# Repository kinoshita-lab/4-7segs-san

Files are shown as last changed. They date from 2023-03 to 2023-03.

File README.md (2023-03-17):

# 4-7segs-san kit

[Document in Japanese](README_ja.md)

4-7segs-san is a handy PCB with 4-digit 7-segment LEDs with decimal point.
You can speed up your MCU project with displaying numbers such as BPM, Level, etc.

## Main Features

- Only 2 GPIO pins required, connected to built in LED Driver(TM1640)
- Compatible for both 5V and 3.3V with builting buffers for signal,  DC-DC converter for power sourcing.
- Easy to use with [dedicated Arduino library for TM1640](./soft/4-7segs-san/TM1640.h)

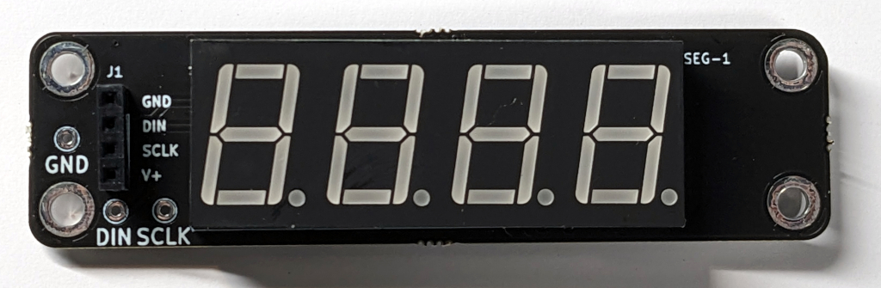
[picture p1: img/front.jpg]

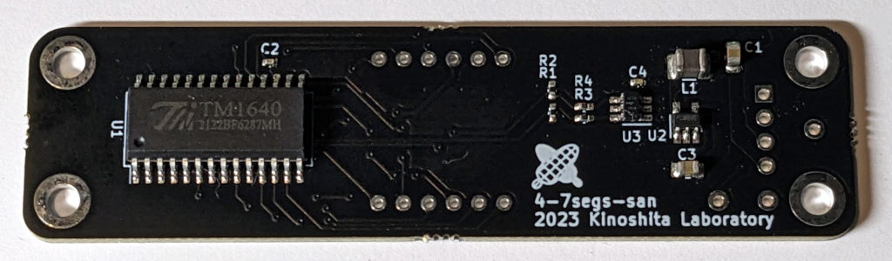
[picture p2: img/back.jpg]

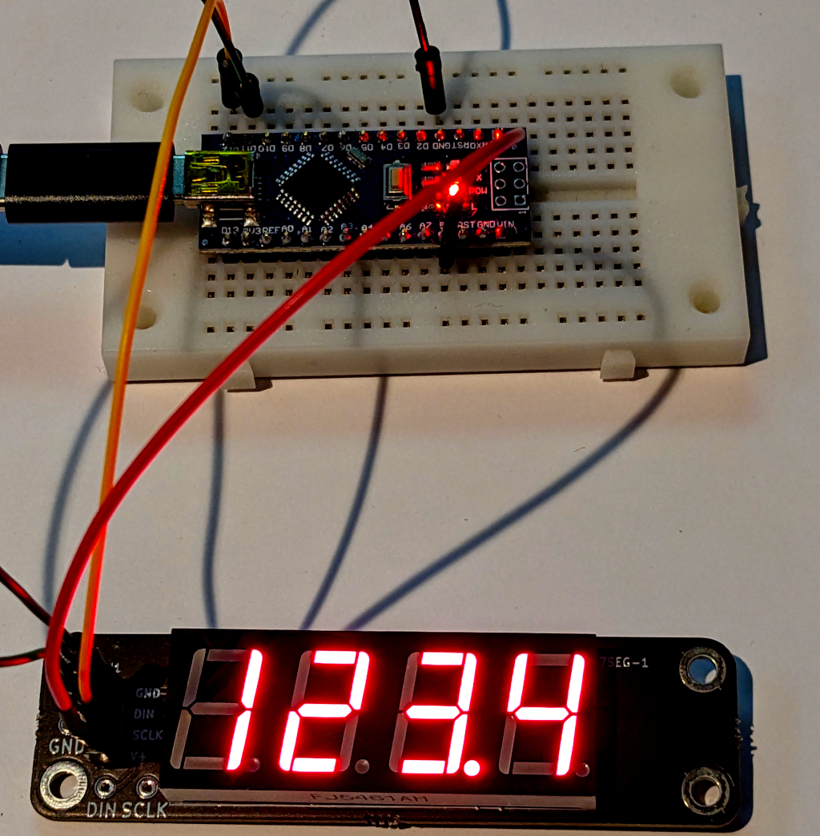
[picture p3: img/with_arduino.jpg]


## Kit Contents

- Pre-assembled circuit board
- [4 digit common cathode segment display](https://www.lcsc.com/product-detail/_Shenzhen-Zhihao-Elec-_C54396.html)
- 1x4 pin socket

## How to assemble

1. Cut all the pins on LED display to approx. 5mm for easier handling.
2. Solder the LED display and pin socket

## Sample program

Please refer to the [soft/4-7segs-san](soft/4-7segs-san)

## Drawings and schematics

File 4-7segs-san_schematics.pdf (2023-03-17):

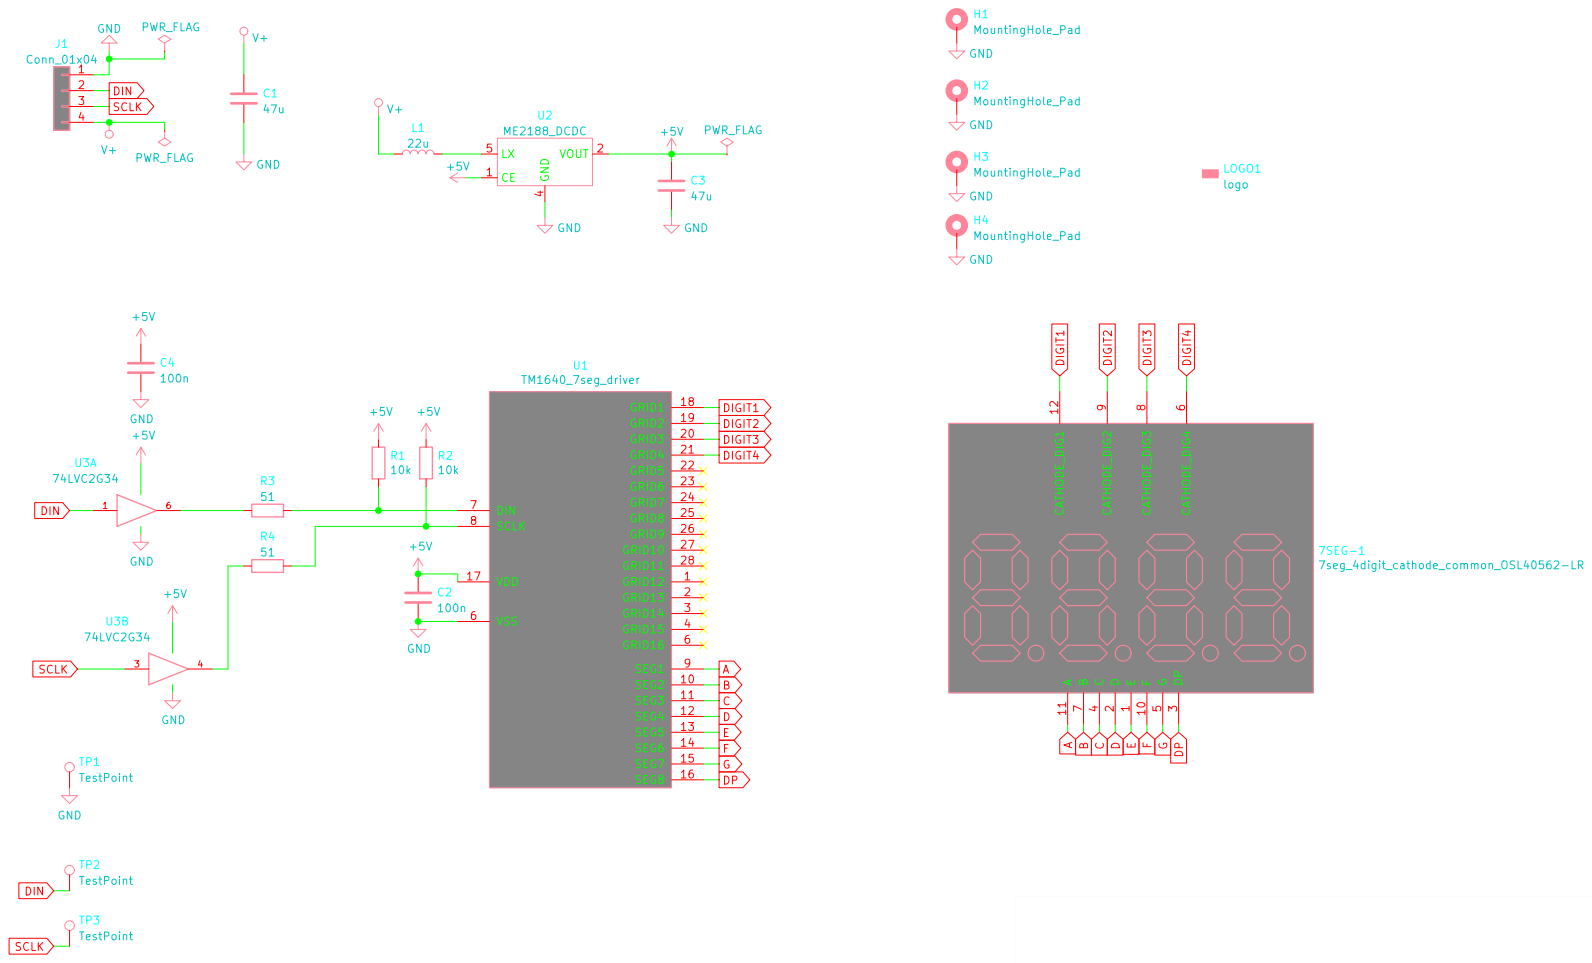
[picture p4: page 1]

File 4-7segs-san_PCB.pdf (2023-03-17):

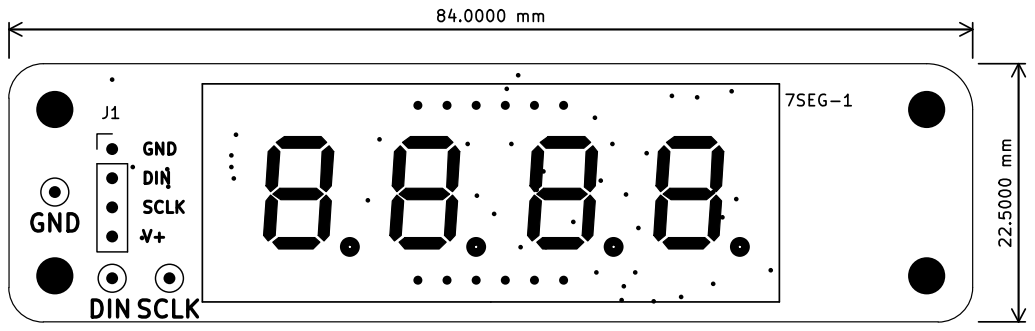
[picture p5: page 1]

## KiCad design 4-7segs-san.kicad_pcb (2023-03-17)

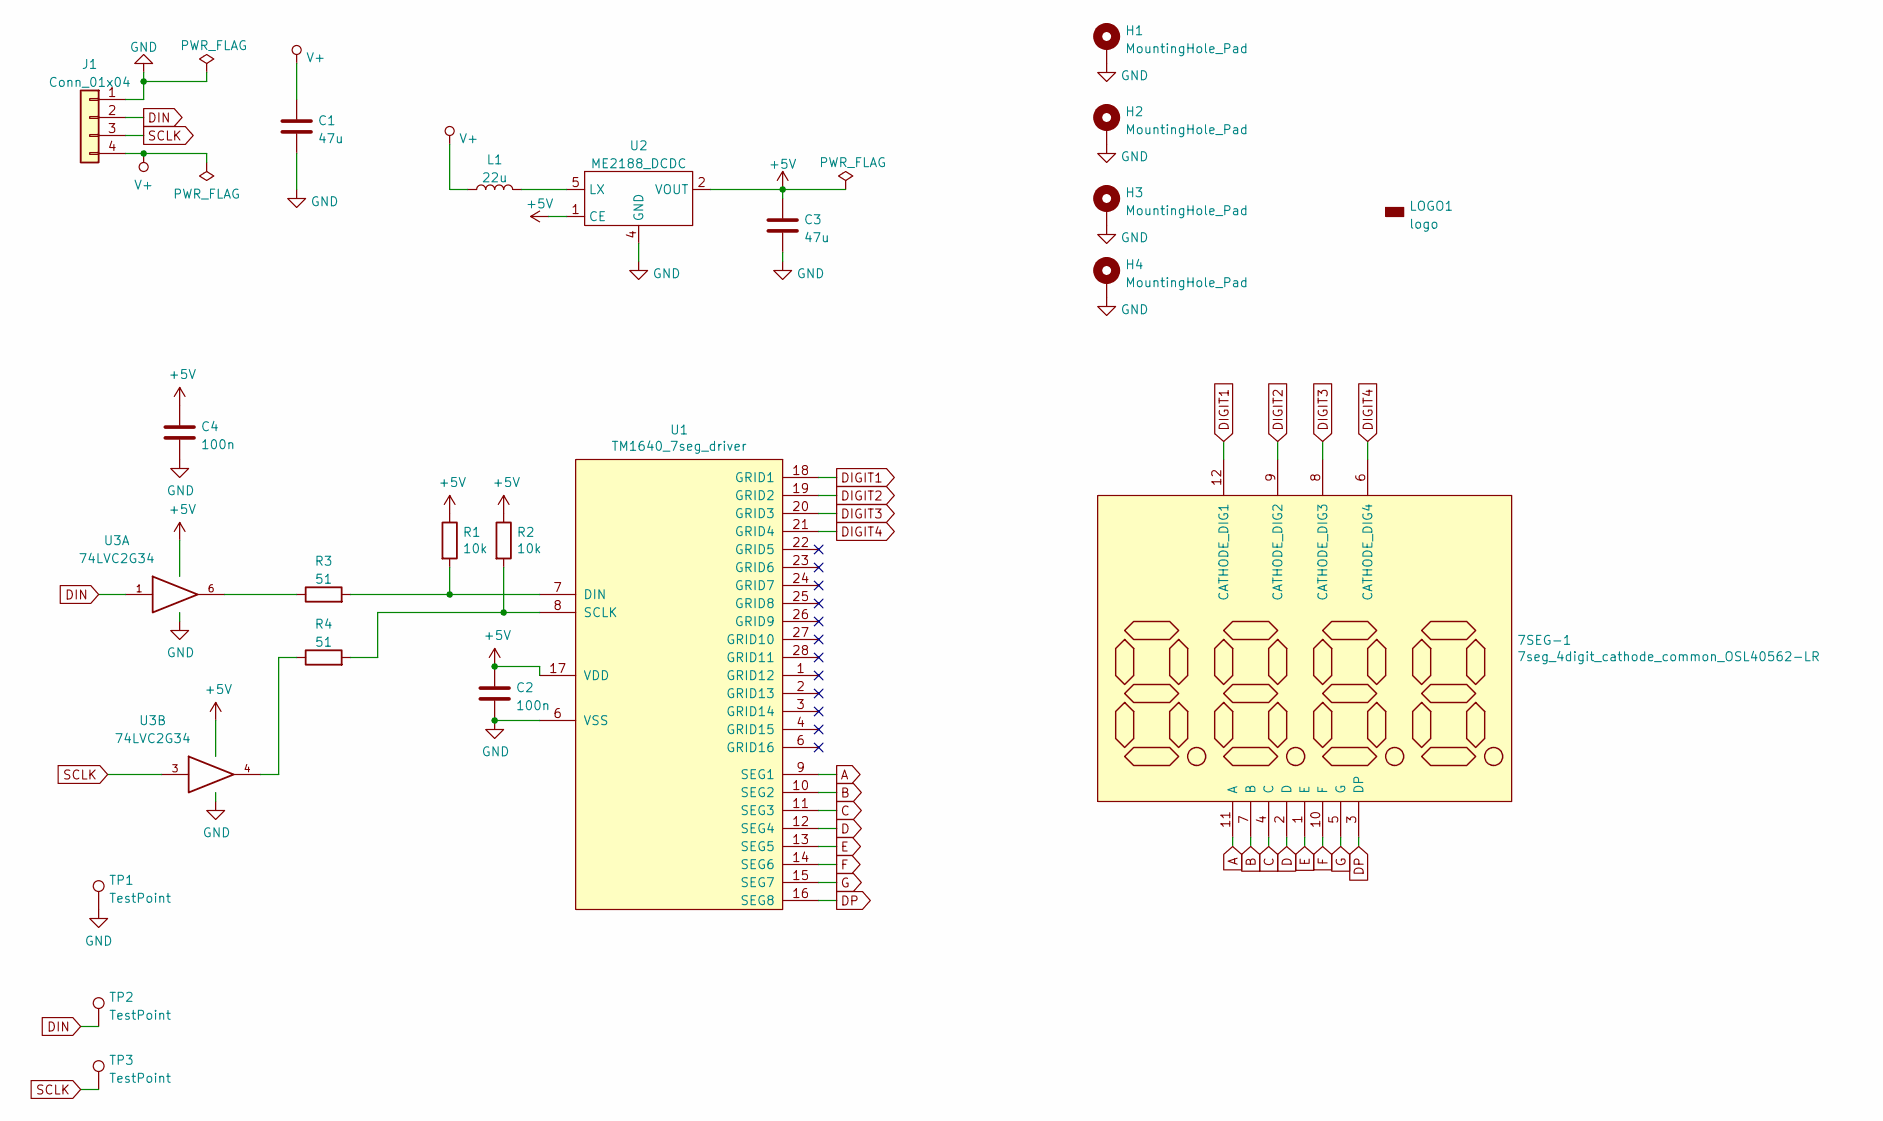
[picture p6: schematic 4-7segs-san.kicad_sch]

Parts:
7SEG-1: 7seg_4digit_cathode_common_OSL40562-LR; LCSC C54396
C1, C3: 47u; C_0805_2012Metric_Pad1.18x1.45mm_HandSolder; LCSC C16780
C2, C4: 100n; C_0402_1005Metric; LCSC C1525
H1, H2, H3, H4: MountingHole_Pad; MountingHole_3.2mm_M3_DIN965_Pad
J1: Conn_01x04; PinHeader_1x04_P2.54mm_Vertical; LCSC C5116530
L1: 22u; R_1210_3225Metric_Pad1.30x2.65mm_HandSolder; LCSC C223225
LOGO1: logo; kinoshita-logo_simplified_600dpi
R1, R2: 10k; R_0402_1005Metric_Pad0.72x0.64mm_HandSolder; LCSC C25744
R3, R4: 51; R_0402_1005Metric_Pad0.72x0.64mm_HandSolder; LCSC C25125
TP1, TP2, TP3: TestPoint; TestPoint_THTPad_D2.0mm_Drill1.0mm
U1: TM1640_7seg_driver; SOIC-28W_7.5x18.7mm_P1.27mm; LCSC C41327
U2: ME2188_DCDC; SOT-23-5_HandSoldering; LCSC C236768
U3: 74LVC2G34; SOT-23-6_Handsoldering; LCSC C347589

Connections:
+5V: C2.1, C3.1, C4.1, R1.1, R2.1, U1.17 (VDD), U2.1 (CE), U2.2 (VOUT), U3.5 (VCC)
A: 7SEG-1.11 (A), U1.9 (SEG1)
B: 7SEG-1.7 (B), U1.10 (SEG2)
C: 7SEG-1.4 (C), U1.11 (SEG3)
D: 7SEG-1.2 (D), U1.12 (SEG4)
DIGIT1: 7SEG-1.12 (CATHODE_DIG1), U1.18 (GRID1)
DIGIT2: 7SEG-1.9 (CATHODE_DIG2), U1.19 (GRID2)
DIGIT3: 7SEG-1.8 (CATHODE_DIG3), U1.20 (GRID3)
DIGIT4: 7SEG-1.6 (CATHODE_DIG4), U1.21 (GRID4)
DIN: J1.2, TP2.1, U3.1
DP: 7SEG-1.3 (DP), U1.16 (SEG8)
E: 7SEG-1.1 (E), U1.13 (SEG5)
F: 7SEG-1.10 (F), U1.14 (SEG6)
G: 7SEG-1.5 (G), U1.15 (SEG7)
GND: C1.2, C2.2, C3.2, C4.2, H1.1, H2.1, H3.1, H4.1, J1.1, TP1.1, U1.6 (VSS), U2.4 (GND), U3.2 (GND)
unnamed: L1.2, U2.5 (LX)
unnamed: R1.2, R3.2, U1.7 (DIN)
unnamed: R2.2, R4.2, U1.8 (SCLK)
unnamed: R3.1, U3.6
unnamed: R4.1, U3.4
SCLK: J1.3, TP3.1, U3.3
VCC1: C1.1, J1.4, L1.1

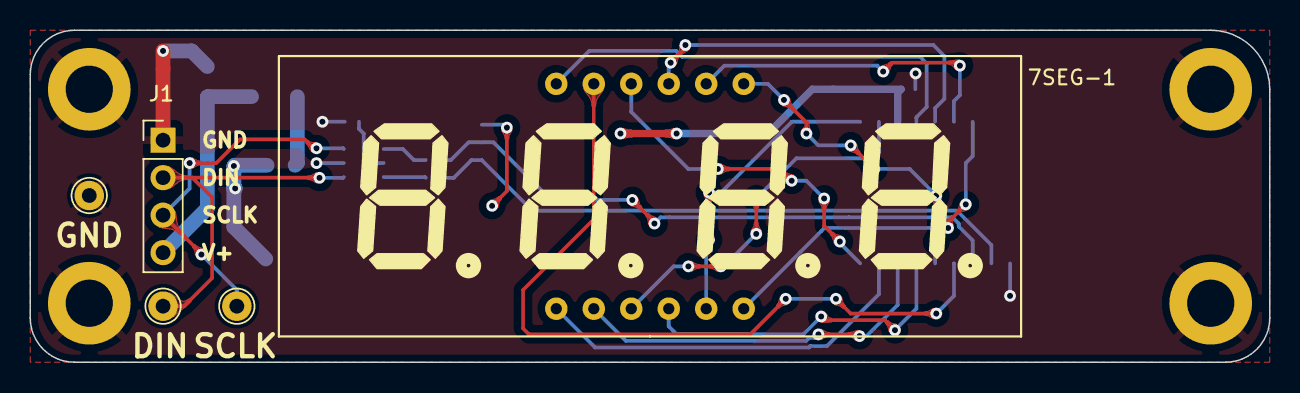
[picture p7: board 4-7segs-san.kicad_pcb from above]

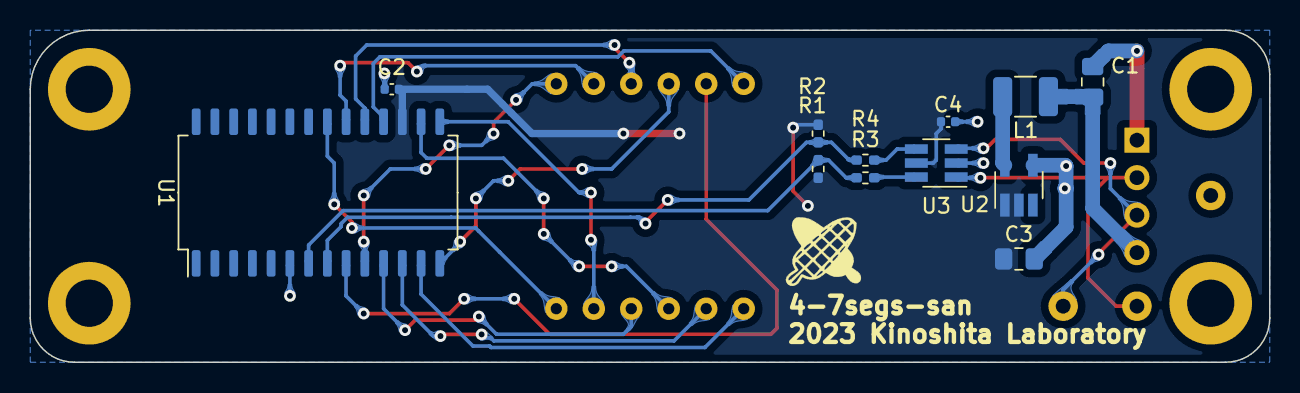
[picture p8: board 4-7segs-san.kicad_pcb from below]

Board: 2 copper layers, 84.0 x 22.5 mm, 22 parts (13 on the bottom side), 22 nets.

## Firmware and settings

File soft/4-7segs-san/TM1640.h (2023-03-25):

/**
 * @file TM1640.h
 * @brief TM1640 LED Driver Library(header only)
 * 

MIT License

Copyright (c) 2023 Kinoshita Laboratory

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
THE SOFTWARE IS PROVIDED "AS IS", WITHOUT WARRANTY OF ANY KIND, EXPRESS OR
IMPLIED, INCLUDING BUT NOT LIMITED TO THE WARRANTIES OF MERCHANTABILITY,
FITNESS FOR A PARTICULAR PURPOSE AND NONINFRINGEMENT. IN NO EVENT SHALL THE
AUTHORS OR COPYRIGHT HOLDERS BE LIABLE FOR ANY CLAIM, DAMAGES OR OTHER
LIABILITY, WHETHER IN AN ACTION OF CONTRACT, TORT OR OTHERWISE, ARISING FROM,
OUT OF OR IN CONNECTION WITH THE SOFTWARE OR THE USE OR OTHER DEALINGS IN THE
SOFTWARE.
 */
#pragma once
#include <stdint.h>
#include <Arduino.h>

namespace kinoshita_lab
{

class TM1640
{
private:
    uint8_t Din_Pin;
    uint8_t Sclk_Pin;

    enum
    {
        NUM_DIGITS = 4,
    };

    enum
    { //               dGFEDCBA
        DIGIT_0    = 0b00111111,
        DIGIT_1    = 0b00000110,
        DIGIT_2    = 0b01011011,
        DIGIT_3    = 0b01001111,
        DIGIT_4    = 0b01100110,
        DIGIT_5    = 0b01101101,
        DIGIT_6    = 0b01111101,
        DIGIT_7    = 0b00000111,
        DIGIT_8    = 0b01111111,
        DIGIT_9    = 0b01101111,
        DIGIT_DP   = 0b10000000, // use it with OR binary operation
        ALL_OFF    = 0b00000000,
        MINUS_SIGN = 0b01000000, // set -1 to display minus sign

        //         dGFEDCBA
        CHAR_A = 0b01110111,
        CHAR_B = 0b01111100, // 'b'
        CHAR_C = 0b00111001,
        CHAR_D = 0b01011110, // 'd'
        CHAR_E = 0b01111001,
        CHAR_F = 0b01110001,
        CHAR_G = 0b00111101,
        CHAR_H = 0b01110110,
        CHAR_I = 0b00000110,
        CHAR_J = 0b00011110,
        CHAR_K = 0b01110110, // 'K' and 'H' are same
        CHAR_L = 0b00111000,
        CHAR_M = 0b00010101,
        CHAR_N = 0b00110111,
        CHAR_O = 0b00111111,
        CHAR_P = 0b01110011,
        CHAR_Q = 0b01100111, // 'q'
        CHAR_R = 0b01010000, // 'r'
        CHAR_S = 0b01101101,
        CHAR_T = 0b01000100, // 't'
        CHAR_U = 0b00011100, // 'u'
        CHAR_V = 0b00011100, // 'v' and 'u' are same
        CHAR_W = 0b00011100, // 'w' and 'u' are same
        CHAR_X = 0b01110110, // 'x' and 'h' are same
        CHAR_Y = 0b01101110,
        CHAR_Z = 0b01011011,
    };

    // note: implement this if required.
    // arduino uno/nano OK
    // seeeduino xiao OK
    void wait()
    {
        //delay(1);
    }

    uint8_t toLedPattern(const int8_t number)
    {
        switch (number) {
        case 0:
            return DIGIT_0;
        case 1:
            return DIGIT_1;
        case 2:
            return DIGIT_2;
        case 3:
            return DIGIT_3;
        case 4:
            return DIGIT_4;
        case 5:
            return DIGIT_5;
        case 6:
            return DIGIT_6;
        case 7:
            return DIGIT_7;
        case 8:
            return DIGIT_8;
        case 9:
            return DIGIT_9;
        case SPECIAL_NUMBER_MINUS_SIGN:
            return MINUS_SIGN;
        case SPECIAL_NUMBER_ALL_OFF:
            return ALL_OFF;
        case 'A': // fall through
        case 'a':
            return CHAR_A;
        case 'B': // fall through
        case 'b':
            return CHAR_B;
        case 'C': // fall through
        case 'c':
            return CHAR_C;
        case 'D': // fall through
        case 'd':
            return CHAR_D;
        case 'E': // fall through
        case 'e':
            return CHAR_E;
        case 'F': // fall through
        case 'f':
            return CHAR_F;
        case 'G': // fall through
        case 'g':
            return CHAR_G;

        case 'H': // fall through
        case 'h':
            return CHAR_H;
        case 'I': // fall through
        case 'i':
            return CHAR_I;
        case 'J': // fall through
        case 'j':
            return CHAR_J;
        case 'K': // fall through
        case 'k':
            return CHAR_K;
        case 'L': // fall through
        case 'l':
            return CHAR_L;
        case 'M': // fall through
        case 'm':
            return CHAR_M;
        case 'N': // fall through
        case 'n':
            return CHAR_N;
        case 'O': // fall through
        case 'o':
            return CHAR_O;
        case 'P': // fall through
        case 'p':
            return CHAR_P;
        case 'Q': // fall through
        case 'q':
            return CHAR_Q;
        case 'R': // fall through
        case 'r':
            return CHAR_R;
        case 'S': // fall through
        case 's':
            return CHAR_S;
        case 'T': // fall through
        case 't':
            return CHAR_T;
        case 'U': // fall through
        case 'u':
            return CHAR_U;
        case 'V': // fall through
        case 'v':
            return CHAR_V;
        case 'W': // fall through
        case 'w':
            return CHAR_W;
        case 'X': // fall through
        case 'x':
            return CHAR_X;
        case 'Y': // fall through
        case 'y':
            return CHAR_Y;
        case 'Z': // fall through
        case 'z':
            return CHAR_Z;
        case ' ':
            return ALL_OFF;
        default:
            return 0;
        }
    }

    void startCondition()
    {
        digitalWrite(Din_Pin, LOW);
        wait();
        digitalWrite(Sclk_Pin, LOW);
    }

    void endCondition()
    {
        digitalWrite(Sclk_Pin, HIGH);
        wait();
        digitalWrite(Din_Pin, HIGH);
        wait();
    }

    void sendBit(const uint8_t bit)
    {
        digitalWrite(Sclk_Pin, LOW);
        wait();
        digitalWrite(Din_Pin, bit);
        wait();
        digitalWrite(Sclk_Pin, HIGH);
        wait();
        digitalWrite(Sclk_Pin, LOW);
        wait();
        digitalWrite(Din_Pin, LOW);
        wait();
    }

    void sendByte(uint8_t data)
    {
        for (auto i = 0; i < 8; ++i) {
            const auto bit = data & 0x01;
            sendBit(bit);
            data >>= 1;
        }
    }

    bool changed      = false;
    bool enabled      = true;
    int decimal_point = -1;
    uint8_t patterns[NUM_DIGITS];
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
